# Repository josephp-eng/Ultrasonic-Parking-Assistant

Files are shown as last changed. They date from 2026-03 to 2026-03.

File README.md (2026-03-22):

# STM32 Ultrasonic Parking Assistant
**Author:** Joseph Pokuta

**Course:** Embedded Microcontrollers (EE3174) | Michigan Technological University

**Date:** 12/03/25

System Demo

This project implements a real-time distance-sensing parking aid designed for the STM32L152RE (ARM Cortex-M3) platform. The system provides immediate visual and auditory feedback to assist drivers in obstructed or low-visibility environments. It was developed as a complete embedded solution, spanning from initial KiCad schematic design to a hand-soldered hardware prototype.

Uses buzzers, lights, an LCD screen, and an ultrasonic sensor to provide a simple yet effective reverse-parking assistant.

*This project was completed for my Embedded Microcontrollers class at Michigan Tech. Be aware that the project files are named with 'EE3174' and 'JP' exactly how they were submitted for the class.*

## System Capabilities
* **Dynamic Range Calibration:** A 10k potentiometer is polled via ADC1 to set the "STOP" distance threshold (20cm - 150cm) in real time.
* **Signal Conditioning:** Implements a median-of-3 filter to eliminate ultrasonic sensor noise and software hysteresis to prevent LED/LCD flickering at band boundaries.
* **Contextual User Interface:** A single interrupt-driven button supports short-press (Mute) and long-press (System Enable/Disable) actions.
* **Non-Blocking Logic:** The buzzer PWM and LCD I2C updates are managed via state-machine logic to ensure the system remains responsive without utilizing CPU-halting delays.

| State | Visual | Description |
| :--- | :--- | :--- |
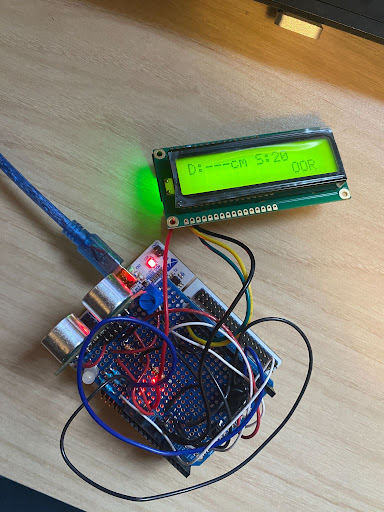
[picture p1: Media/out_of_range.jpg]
Out of Range
| **Out of Range (OOR)** |  | Active when objects are >60cm away. The system enters a low-activity state to prevent needless power draw and noise. |
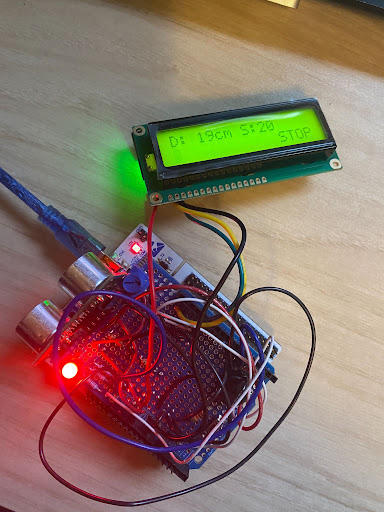
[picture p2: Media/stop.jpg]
Stop State
| **Optimal Stop** |  | Indicates the vehicle has reached the precise "Stop" distance (e.g., 20cm) as calibrated by the user via the potentiometer. |

## Hardware Spec
The hardware was designed in KiCad and hand-soldered onto a protoboard shield.

[Hardware Schematic](Media/project_layout.jpg)

### Pin Mapping
| Peripheral | STM32 Pin | Mode | Purpose |
| :--- | :--- | :--- | :--- |
| **HC-SR04 Echo** | PA0 | TIM2 Input Capture | Measures pulse width for distance calculation |
| **HC-SR04 Trig** | PA9 | GPIO Output | Generates 12us trigger pulse |
| **I2C LCD** | PB8 / PB9 | I2C1 | Interface for MCP23008 Port Expander |
| **RGB LED** | PB13 - PB15 | GPIO Output | Tri-color visual proximity indicator |
| **Buzzer** | PB4 | TIM3 CH1 (PWM) | Variable frequency audio feedback |
| **Potentiometer** | PA4 | ADC1 | Real-time "Stop" threshold calibration |
| **User Button** | PA8 | EXTI (Interrupt) | Short press: Mute / Long press: Power |

### Bill of Materials
* 1x STM32L152RE Nucleo-64
* 1x HC-SR04 Ultrasonic Sensor
* 1x 16x2 Character LCD (I2C)
* 1x Common-Anode RGB LED
* 1x Piezo Buzzer
* 1x 10k Ohm Potentiometer
* 1x Momentary Tactile Switch
* 1x Protoboard Shield

## Challenges and Debugging
The transition from schematic to a soldered prototype involved significant hardware troubleshooting:
* **Voltage Rail Optimization:** Initial smoke testing revealed that the HC-SR04 and I2C LCD were underperforming on the 3.3V rail. The power domain was shifted to 5V while maintaining logic compatibility with the STM32's 5V-tolerant pins, resulting in stable sensor pings and clear LCD contrast.
* **Hardware Isolation:** A grounding failure on the piezo buzzer was identified late in the assembly phase. By isolating the buzzer subsystem and performing continuity tests, the fault was traced to a cold solder joint on the common ground plane and rectified.
* **OOR Logic:** Specialized handling was implemented for Out-of-Range measurements to prevent the system from reporting "ghost" distances or running the UI unnecessarily when the path is clear.

### Logic Flow
```mermaid
graph TD
    A[Start] --> B[Initialize Peripherals]
    B --> C[Self-Test: Buzzer Chirp]
    C --> D[Loop]
    D --> E[Read ADC: Update Stop Threshold]
    E --> F[Trigger HC-SR04 Sensor]
    F --> G[TIM2 Capture: Pulse Calculation]
    G --> H[Apply Median Filter & Hysteresis]
    H --> I{Distance Analysis}
    I --> J[Update RGB LED & Buzzer PWM]
    J --> K[Update LCD Cache]
    K --> D
```

## How to Run

### Hardware
* Wire the components according the to **Pin Mapping** table and the KiCad schematic `project_layout.jpg`
* Connect the STM32 Nucleo-64 board via Mini-USB to your device

### Software
* Open **STM32CubeIDE**.
* Import the project from the `/final_parkingAssistant_JP` directory.
* Open the `.ioc` file to verify the Clock Configuration (ensure the HCLK is set correctly for the Timer prescalers).
* Build the project to generate the `.elf` or `.bin` file.
* Connect your Nucleo board and click **Run** to flash the firmware.

### Usage
* Upon startup, the system will perform a short buzzer "chirp" to confirm the PWM and Piezo are functional.
* Adjust the **Potentiometer** to set your desired stopping distance.
* Use the **Button** to toggle the mute state ('M') or long-press to enter standby mode.

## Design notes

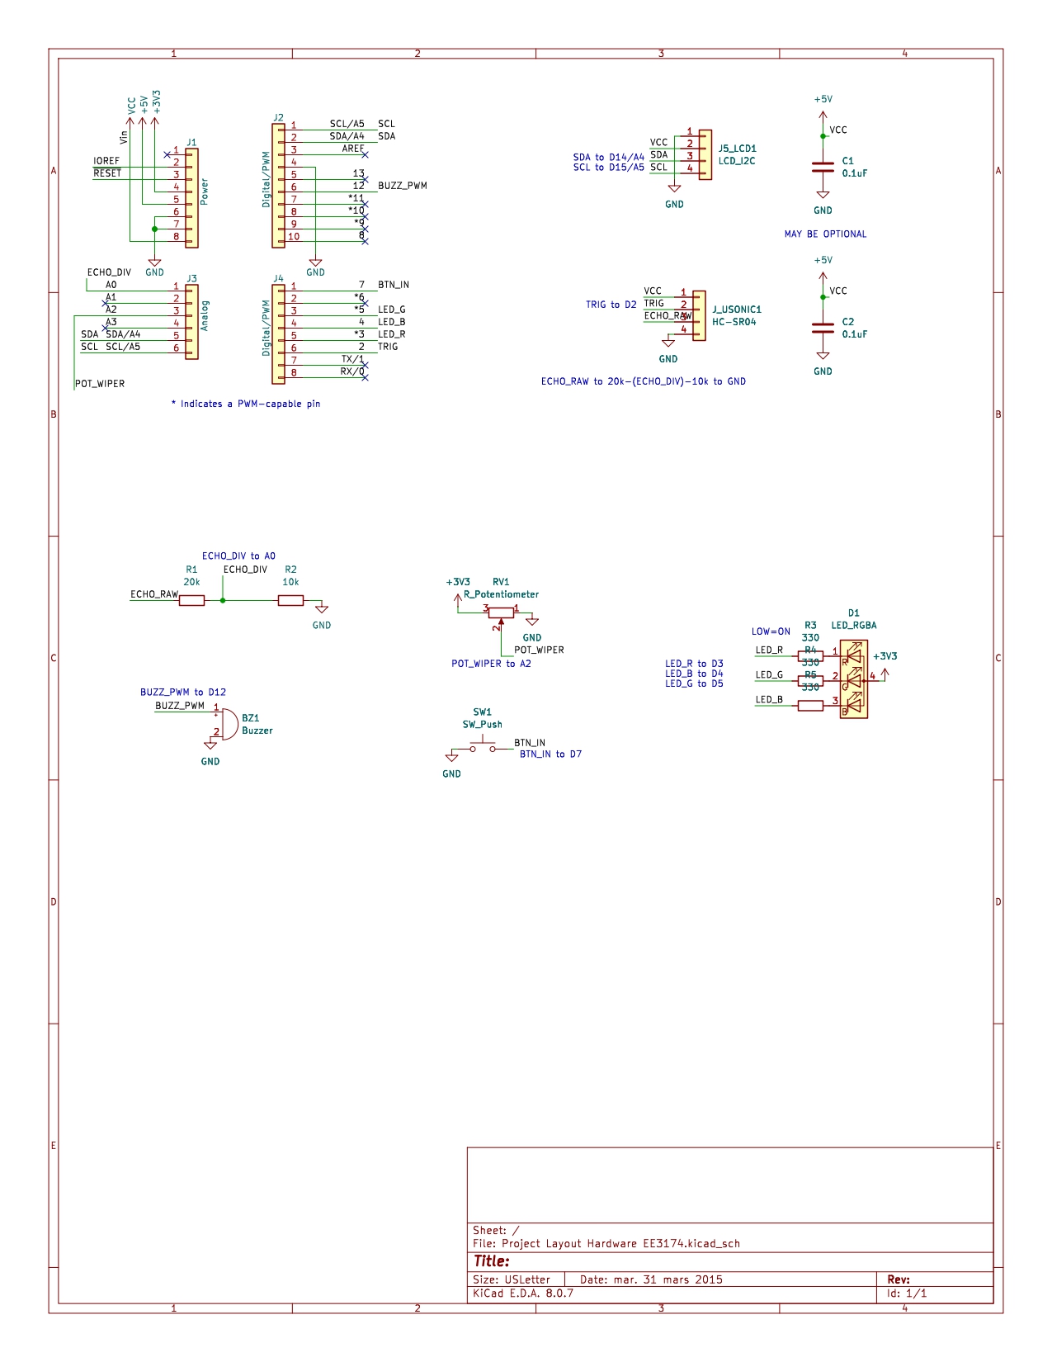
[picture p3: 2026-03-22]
Media/project_layout.jpg

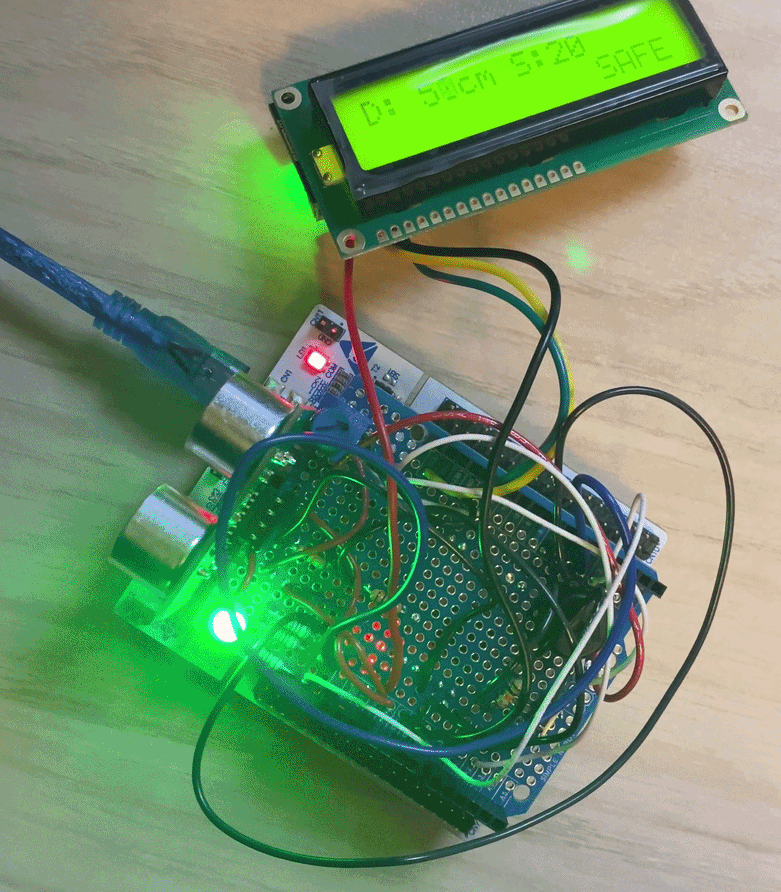
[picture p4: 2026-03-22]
Media/good.png

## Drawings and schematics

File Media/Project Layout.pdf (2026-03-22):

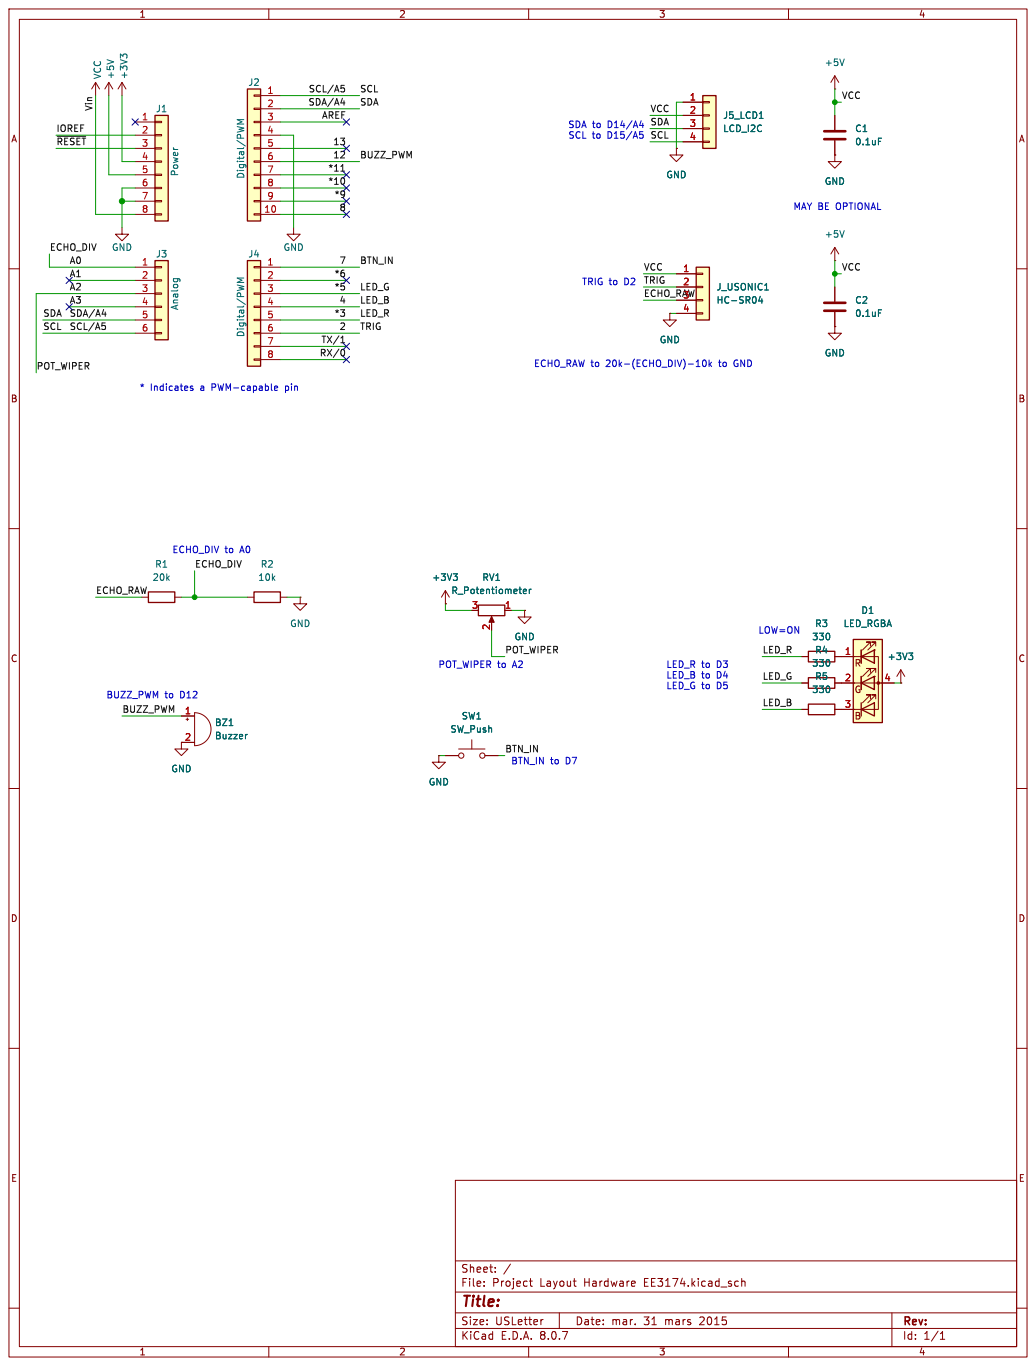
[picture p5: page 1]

SDA to D14/A4 SCL to D15/A5

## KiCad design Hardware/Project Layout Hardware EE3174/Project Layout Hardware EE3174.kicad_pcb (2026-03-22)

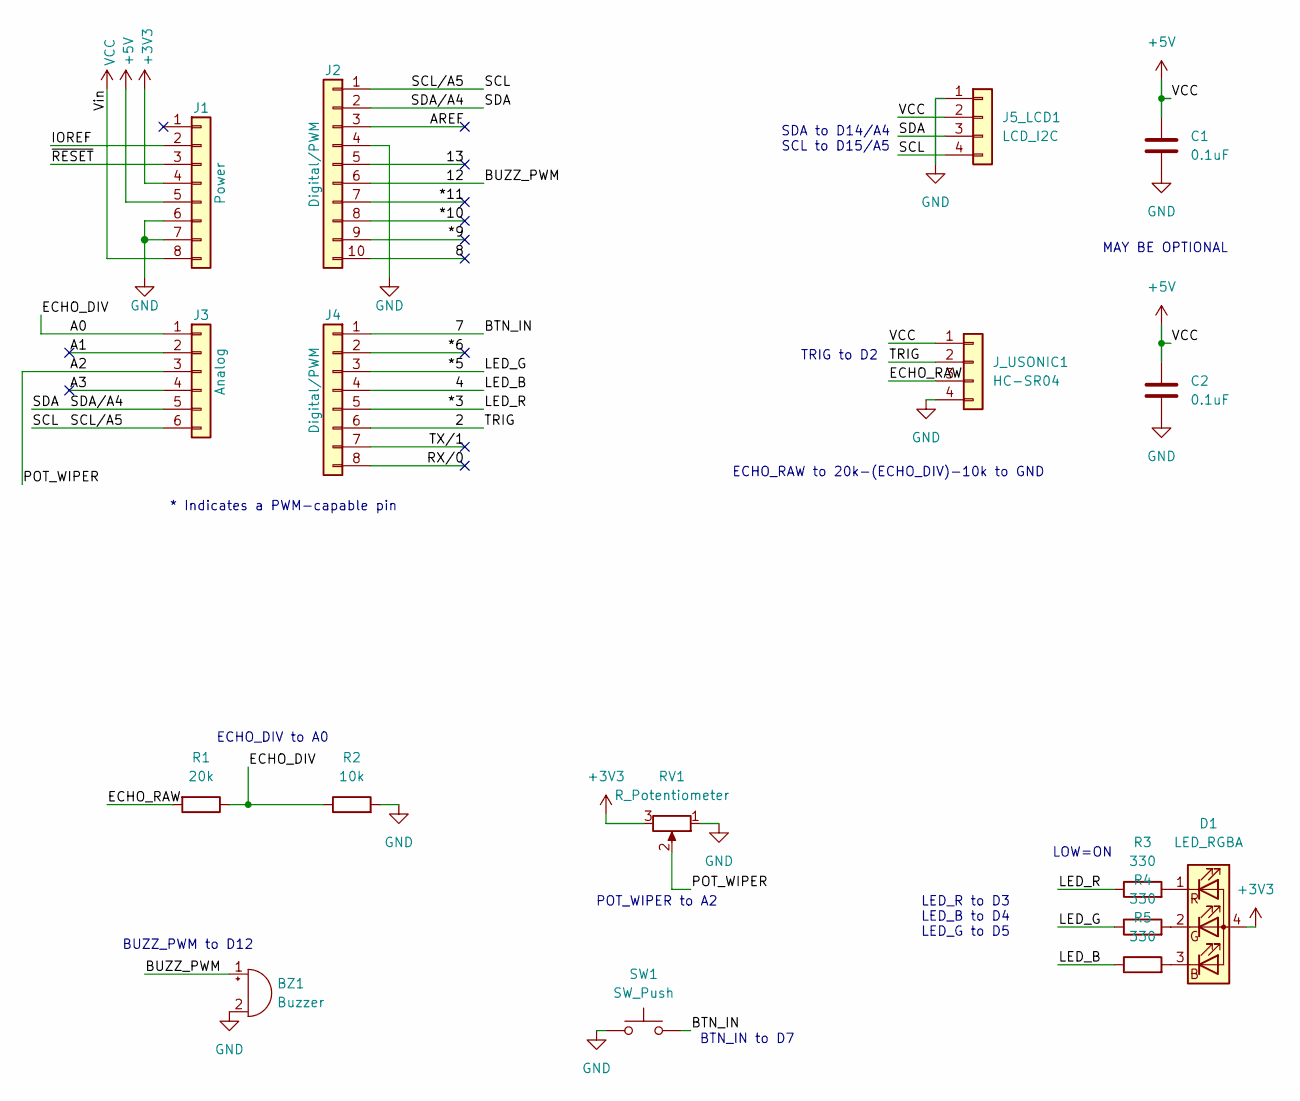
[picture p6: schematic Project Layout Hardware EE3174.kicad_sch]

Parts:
BZ1: Buzzer; Buzzer_12x9.5RM7.6
C1, C2: 0.1uF; C_Disc_D3.0mm_W2.0mm_P2.50mm
D1: LED_RGBA; LED_D5.0mm-4_RGB
J1: Power; PinSocket_1x08_P2.54mm_Vertical
J2: Digital/PWM; PinSocket_1x10_P2.54mm_Vertical
J3: Analog; PinSocket_1x06_P2.54mm_Vertical
J4: Digital/PWM; PinSocket_1x08_P2.54mm_Vertical
J5_LCD1: LCD_I2C; PinHeader_1x04_P2.54mm_Vertical
J_USONIC1: HC-SR04; PinHeader_1x04_P2.54mm_Vertical
R1: 20k; R_Axial_DIN0207_L6.3mm_D2.5mm_P7.62mm_Horizontal
R2: 10k; R_Axial_DIN0207_L6.3mm_D2.5mm_P7.62mm_Horizontal
R3, R4, R5: 330; R_Axial_DIN0207_L6.3mm_D2.5mm_P7.62mm_Horizontal
RV1: R_Potentiometer; Potentiometer_Alps_RK09K_Single_Vertical
SW1: SW_Push; SW_PUSH_6mm

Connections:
+3V3: D1.4 (A), J1.4, RV1.3
+5V: C1.1, C2.1, J1.5, J1.8, J5_LCD1.2, J_USONIC1.1 (VCC)
/2: J4.6, J_USONIC1.2 (TRIG)
/4: J4.4, R5.1
/7: J4.1, SW1.2
/8: J2.10
/12: BZ1.1 (+), J2.6
/13: J2.5
/*3: J4.5, R3.1
/*5: J4.3, R4.1
/*6: J4.2
/*9: J2.9
/*10: J2.8
/*11: J2.7
/A0: J3.1, R1.1, R2.1
/A1: J3.2
/A2: J3.3, RV1.2
/A3: J3.4
/AREF: J2.3
/ECHO_RAW: J_USONIC1.3 (ECHO), R1.2
/IOREF: J1.2
/RX/0: J4.8
/SCL: J2.1, J3.6, J5_LCD1.4
/SDA: J2.2, J3.5, J5_LCD1.3
/TX/1: J4.7
/~RESET: J1.3
GND: BZ1.2 (-), C1.2, C2.2, J1.6, J1.7, J2.4, J5_LCD1.1, J_USONIC1.4 (GND), R2.2, RV1.1, SW1.1
unnamed: D1.3 (BK), R5.2
unnamed: D1.2 (GK), R4.2
unnamed: D1.1 (RK), R3.2

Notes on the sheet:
BUZZ_PWM to D12
MAY BE OPTIONAL
TRIG to D2
BTN_IN to D7
SDA to D14/A4 SCL to D15/A5
LED_R to D3 LED_B to D4 LED_G to D5
ECHO_DIV to A0
LOW=ON
* Indicates a PWM-capable pin
ECHO_RAW to 20k-(ECHO_DIV)-10k to GND
POT_WIPER to A2

Board: 2 copper layers, 21 parts (0 on the bottom side), 17 nets, no tracks yet.

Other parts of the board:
MH1, MH2, MH3, MH4: MountingHole_3.2mm

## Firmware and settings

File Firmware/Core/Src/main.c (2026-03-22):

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
/* Includes ------------------------------------------------------------------*/
#include "main.h"

/* USER CODE BEGIN Includes */
#include <stdio.h>
#include <string.h>
/* USER CODE END Includes */

/* USER CODE BEGIN PD */
// ---- UI / logic constants ----
// Hysteresis for OOR: once you're "out", you must come back below OOR_EXIT_CM to re-enter range.
#define OOR_ENTER_CM    60    // distance >= this -> go OOR
#define OOR_EXIT_CM     56    // distance <= this -> back in range

#define OUT_MAX_CM      OOR_ENTER_CM   // leave this name for existing code paths (LCD/buzzer)
#define SLOW_BAND_CM    25    // stop_cm..stop_cm+25 = "SLOW"; else "SAFE"
#define BAR_LEN         12    // meter cells on 2nd line
#define DEBOUNCE_MS     40
#define LONG_PRESS_MS   700   // hold >= this => enable/disable toggle


/* USER CODE END PD */

ADC_HandleTypeDef hadc;

I2C_HandleTypeDef hi2c1;

TIM_HandleTypeDef htim2;
TIM_HandleTypeDef htim3;

UART_HandleTypeDef huart2;

/* USER CODE BEGIN PV */
// ---- Ultrasonic shared state (EXTI + TIM2) ----
volatile uint32_t t_rise = 0, t_fall = 0;
volatile uint8_t  echo_done = 0;       // set on falling edge
volatile uint32_t us_pulse = 0;        // pulse width in us
volatile uint16_t cm10     = 0;        // distance in 0.1 cm (integer)

// ---- Pot values ----
volatile uint16_t pot_raw = 0;         // 0..4095
volatile uint16_t stop_cm = 60;        // user "stop" setpoint (cm), from pot

// ---- Buzzer pattern (non-blocking) ----
uint32_t beep_next_ms = 0;
uint16_t beep_on_ms   = 60;
uint16_t beep_off_ms  = 300;

// ---- App state ----
volatile uint8_t  system_enabled = 1;   // long-press toggles this
volatile uint8_t  buzzer_muted   = 0;   // short-press toggles this

// ---- Button (PA8) edge tracking ----
volatile uint8_t  btn_down = 0;
volatile uint32_t btn_t0   = 0;

// ---- MCP23008 LCD port mirror (backlight on) ----
static uint8_t mcp_port = (1u<<7);     // LCD_BL

// Line caches to avoid flicker (16 chars + NUL)
static char line0_prev[17] = "                ";
static char line1_prev[17] = "                ";
static uint32_t next_lcd_ms = 0;

/* USER CODE END PV */

void SystemClock_Config(void);
static void MX_GPIO_Init(void);
static void MX_USART2_UART_Init(void);
static void MX_ADC_Init(void);
static void MX_I2C1_Init(void);
static void MX_TIM2_Init(void);
static void MX_TIM3_Init(void);
/* USER CODE BEGIN PFP */
// microsecond delay via DWT
static void delay_us(uint32_t us);

// ultrasonic
static void usonic_timer_start(void);
static uint8_t usonic_single(void);   // fills us_pulse & cm10, returns 1 if ok

// pot
static uint16_t pot_read_raw(void);
static uint16_t pot_to_stop_cm(uint16_t v); // map 0..4095 -> 20..150 cm

// RGB & buzzer
static void rgb_set(uint8_t r_on, uint8_t g_on, uint8_t b_on); // 1=ON
static void buzzer_on(void);
static void buzzer_off(void);
static void buzzer_update(uint32_t now_ms, uint16_t dist_cm);

// UI helpers (only the drawer is prototyped here;
// lcd_write_line_cached() is defined before use in USER CODE 0)
static void lcd_draw_ui(uint16_t dist_cm, uint16_t stop_cm, uint8_t muted, uint8_t enabled);

// LCD (MCP23008 @ 0x20)
static void lcd_i2c_scan(void);
static HAL_StatusTypeDef mcp_write(uint8_t reg, uint8_t val);
static void mcp_apply(void);
static void lcd_pulseE(void);
static void lcd_write4(uint8_t nibble, uint8_t rs);
static void lcd_write8(uint8_t v, uint8_t rs);
static void lcd_cmd(uint8_t c);
static void lcd_data(uint8_t d);
static void lcd_init_4bit(void);
static void lcd_set_cursor(uint8_t col, uint8_t row);
static void lcd_print(const char *s);
static void lcd_print_u16(uint16_t v);
static void lcd_bar16(uint8_t filled);
static void lcd_clear_line(uint8_t row);
/* USER CODE END PFP */

/* USER CODE BEGIN 0 */
// ---- microsecond delay via DWT cycle counter ----
static void delay_us(uint32_t us){
  static uint8_t ready = 0;
  if(!ready){
    CoreDebug->DEMCR |= CoreDebug_DEMCR_TRCENA_Msk;
    DWT->CYCCNT = 0;
    DWT->CTRL  |= DWT_CTRL_CYCCNTENA_Msk;
    ready = 1;
  }
  const uint32_t cycles_per_us = 32000000u/1000000u; // SYSCLK ~32 MHz
  uint32_t start = DWT->CYCCNT, target = start + us*cycles_per_us;
  while((int32_t)(DWT->CYCCNT - target) < 0) { __NOP(); }
}

// ---- Ultrasonic helpers ----
static void usonic_timer_start(void){
  // TIM2 is Base @ 1 MHz (PSC=31, ARR=65535)
  __HAL_TIM_SET_PRESCALER(&htim2, 31);
  __HAL_TIM_SET_AUTORELOAD(&htim2, 65535);
  __HAL_TIM_SET_COUNTER(&htim2, 0);
  HAL_TIM_Base_Start(&htim2);
  // TRIG idle low
  HAL_GPIO_WritePin(TRIG_GPIO_Port, TRIG_Pin, GPIO_PIN_RESET);
}

// one shot: returns 1 if echo captured, updates us_pulse and cm10
static uint8_t usonic_single(void){
  echo_done = 0;
  // 10–12 us TRIG
  HAL_GPIO_WritePin(TRIG_GPIO_Port, TRIG_Pin, GPIO_PIN_SET);
  delay_us(12);
  HAL_GPIO_WritePin(TRIG_GPIO_Port, TRIG_Pin, GPIO_PIN_RESET);

  // wait up to 40 ms
  uint32_t t0 = HAL_GetTick();
  while(!echo_done){
    if (HAL_GetTick() - t0 > 40) return 0;
  }
  uint32_t arr = __HAL_TIM_GET_AUTORELOAD(&htim2) + 1;
  us_pulse = (t_fall >= t_rise) ? (t_fall - t_rise) : (t_fall + arr - t_rise);
  // distance in 0.1 cm: (us / 58) * 10 = us * 10 / 58
  cm10 = (uint16_t)((us_pulse * 10u) / 58u);
  return 1;
}

// ---- Potentiometer ----
static uint16_t pot_read_raw(void){
  HAL_ADC_Start(&hadc);
  HAL_ADC_PollForConversion(&hadc, 5);
  uint16_t v = (uint16_t)HAL_ADC_GetValue(&hadc);
  HAL_ADC_Stop(&hadc);
  return v;
}
// map 0..4095 -> 20..150 cm (linear)
static uint16_t pot_to_stop_cm(uint16_t v){
  if (v > 4095) v = 4095;
  return (uint16_t)(20u + ((150u - 20u) * (uint32_t)v)/4095u);
}

// ---- RGB (common-anode: LOW=ON) ----
static void rgb_set(uint8_t r_on, uint8_t g_on, uint8_t b_on){
  // drive low to turn ON
  HAL_GPIO_WritePin(RGB_LED1_GPIO_Port, RGB_LED1_Pin, r_on ? GPIO_PIN_RESET : GPIO_PIN_SET);
  HAL_GPIO_WritePin(RGB_LED2_GPIO_Port, RGB_LED2_Pin, g_on ? GPIO_PIN_RESET : GPIO_PIN_SET);
  HAL_GPIO_WritePin(RGB_LED3_GPIO_Port, RGB_LED3_Pin, b_on ? GPIO_PIN_RESET : GPIO_PIN_SET);
}

// ---- Buzzer @ 2 kHz (TIM3 CH1; CCR=50% when ON) ----
static void buzzer_on(void){
  __HAL_TIM_SET_COMPARE(&htim3, TIM_CHANNEL_1, (__HAL_TIM_GET_AUTORELOAD(&htim3)+1)/2);
  HAL_TIM_PWM_Start(&htim3, TIM_CHANNEL_1);
}
static void buzzer_off(void){
  HAL_TIM_PWM_Stop(&htim3, TIM_CHANNEL_1);
}
// --- small median-of-3 helper (robust to one outlier) ---
static uint16_t median3(uint16_t a, uint16_t b, uint16_t c)
{
  if (a > b) { uint16_t t=a; a=b; b=t; }
  if (b > c) { uint16_t t=b; b=c; c=t; }
  if (a > b) { uint16_t t=a; a=b; b=t; }
  return b; // now b is median
}

// ---- UI + LED helpers ------------------------------------------------------

// Color enum and LED setter (common-anode: LOW = ON)
typedef enum { LED_OFF=0, LED_GREEN, LED_YELLOW, LED_RED } LEDColor;

static void set_led_color(LEDColor c)
{
  switch (c) {
    case LED_OFF:    rgb_set(0,0,0); break;
    case LED_GREEN:  rgb_set(0,1,0); break;
    case LED_YELLOW: rgb_set(1,1,0); break; // red+green
    case LED_RED:    rgb_set(1,0,0); break;
  }
}

// Write a full 16-char line only if contents changed (reduces flicker)
static void lcd_write_line_cached(uint8_t row, const char *line16, char prev16[17])
{
  // compare
  if (memcmp(prev16, line16, 16) == 0) return;

  // write
  lcd_set_cursor(0, row);
  for (uint8_t i = 0; i < 16; ++i) {
    lcd_data((uint8_t)line16[i]);
  }

  // cache
  memcpy(prev16, line16, 16);
  prev16[16] = '\0';
}

// Line0: "D:XXcm S:YY " + 'M' at col 15
// Line1: [BAR] + "SAFE/SLOW/STOP" or "OOR "
static void lcd_draw_ui(uint16_t dist_cm, uint16_t stop_cm, uint8_t muted, uint8_t enabled)
{
  extern char line0_prev[17];
  extern char line1_prev[17];
  extern uint32_t next_lcd_ms;

  uint32_t now = HAL_GetTick();
  if ((int32_t)(now - next_lcd_ms) < 0) return;  // rate-limit
  next_lcd_ms = now + 50;                         // ~20 Hz max

  char l0[17]; char l1[17];
  memset(l0, ' ', 16); l0[16] = '\0';
  memset(l1, ' ', 16); l1[16] = '\0';

  if (!enabled) {
    lcd_write_line_cached(0, l0, line0_prev);
    lcd_write_line_cached(1, l1, line1_prev);
    return;
  }

  // ----- Line 0 -----
  const uint8_t invalid = (dist_cm == 999 || dist_cm > OUT_MAX_CM);
  char dstr[4] = "---";
  if (!invalid) snprintf(dstr, sizeof dstr, "%3u", dist_cm);
  char sstr[4]; snprintf(sstr, sizeof sstr, "%-3u", stop_cm);

  l0[0]='D'; l0[1]=':'; memcpy(&l0[2], dstr, 3);
  l0[5]='c'; l0[6]='m'; l0[7]=' ';
  l0[8]='S'; l0[9]=':'; memcpy(&l0[10], sstr, 3);
  l0[15] = muted ? 'M' : ' ';

  // ----- Line 1 -----
  if (invalid) {
    memcpy(&l1[12], "OOR ", 4);
  } else {
    int16_t remain = (int16_t)stop_cm - (int16_t)dist_cm; // >0 when closer than setpoint
    uint8_t fill = (remain <= 0) ? 0 :
                   (remain >= (BAR_LEN*2) ? BAR_LEN : (uint8_t)(remain/2));
    for (uint8_t i=0;i<BAR_LEN && i<16;i++) l1[i] = (i<fill) ? (char)0xFF : ' ';

    const char* status =
      (dist_cm <= stop_cm) ? "STOP" :
      (dist_cm < (uint16_t)(stop_cm + SLOW_BAND_CM)) ? "SLOW" : "SAFE";
    memcpy(&l1[12], status, 4); // fits at columns 12..15
  }

  // push if changed
  lcd_write_line_cached(0, l0, line0_prev);
  lcd_write_line_cached(1, l1, line1_prev);
}


// Final cadence: SAFE = very infrequent, SLOW = ~1 Hz, STOP = continuous tone
static void buzzer_update(uint32_t now_ms, uint16_t dist_cm)
{
  // Global guards
  if (!system_enabled || buzzer_muted || dist_cm == 999 || dist_cm > OUT_MAX_CM) {
    buzzer_off();
    // don't reset state; when re-enabled we’ll re-sync on zone change
    return;
  }

  // Zone selection
  enum { Z_SAFE=0, Z_SLOW, Z_STOP } zone;
  if (dist_cm <= stop_cm) {
    zone = Z_STOP;                 // RED
  } else if (dist_cm < (uint16_t)(stop_cm + SLOW_BAND_CM)) {
    zone = Z_SLOW;                 // YELLOW
  } else {
    zone = Z_SAFE;                 // GREEN
  }

  // Persistent state
  static uint8_t  phase_on = 0;    // 0 = OFF, 1 = ON (for chirps)
  static uint32_t t_next   = 0;    // next toggle timestamp
  static uint8_t  last_zone = 0xFF;

  // STOP => continuous tone
  if (zone == Z_STOP) {
    if (last_zone != Z_STOP) {
      // entering STOP: turn solid ON
      buzzer_on();
      phase_on  = 1;
      // t_next unused while in STOP
    }
    last_zone = Z_STOP;
    return; // keep buzzing continuously
  }

  // If we just left STOP, ensure we start from OFF to make chirps clear
  if (last_zone == Z_STOP && zone != Z_STOP) {
    buzzer_off();
    phase_on = 0;
    t_next   = now_ms; // ready to start new cadence
  }
  last_zone = zone;

  // Per-zone ON/OFF timings (ms)
  // SAFE: ~0.33 Hz => 60 ms ON, 2940 ms OFF (very infrequent)
  // SLOW: ~1.0  Hz => 120 ms ON, 880  ms OFF (clearly more frequent)
  uint16_t on_ms, off_ms;
  if (zone == Z_SLOW) {
    on_ms = 120; off_ms = 880;
  } else { // Z_SAFE
    on_ms = 60;  off_ms = 2940;
  }

  // Initialize first chirp promptly when entering a chirp zone
  static uint8_t initialized = 0;
  if (!initialized) {
    initialized = 1;
    phase_on = 1;
    buzzer_on();
    t_next = now_ms + on_ms;
  }

  // Toggle by schedule
  if ((int32_t)(now_ms - t_next) >= 0) {
    if (phase_on) {
      // go OFF for the rest period
      buzzer_off();
      phase_on = 0;
      t_next = now_ms + off_ms;
    } else {
      // start a chirp
      buzzer_on();
      phase_on = 1;
      t_next = now_ms + on_ms;
    }
  }
}


// ---- LCD (MCP23008 @ 0x20) ----
#define LCD_RS   (1u<<1)
#define LCD_E    (1u<<2)
#define LCD_D4   (1u<<3)
#define LCD_D5   (1u<<4)
#define LCD_D6   (1u<<5)
#define LCD_D7   (1u<<6)
#define LCD_BL   (1u<<7)
#define MCP_ADDR (0x20u<<1)
#define MCP_IODIR 0x00
#define MCP_GPIO  0x09

static void lcd_i2c_scan(void){
  volatile uint8_t seen = 0;
  for(uint8_t a=0x03;a<0x78;a++){
    if(HAL_I2C_IsDeviceReady(&hi2c1, a<<1, 1, 5)==HAL_OK){
      if (a==0x20) seen=1;
    }
  }
  (void)seen; // set a breakpoint to verify seen==1
}
static HAL_StatusTypeDef mcp_write(uint8_t reg, uint8_t val){
  uint8_t buf[2] = {reg, val};
  return HAL_I2C_Master_Transmit(&hi2c1, MCP_ADDR, buf, 2, 50);
}
static void mcp_apply(void){ (void)mcp_write(MCP_GPIO, mcp_port); }
static void lcd_pulseE(void){
  mcp_port |= LCD_E;  mcp_apply();
  for(volatile int i=0;i<160;i++) __NOP();
  mcp_port &= ~LCD_E; mcp_apply();
}
static void lcd_write4(uint8_t nibble, uint8_t rs){
  mcp_port &= ~(LCD_D4|LCD_D5|LCD_D6|LCD_D7|LCD_RS);
  if (rs) mcp_port |= LCD_RS;
  if (nibble & 0x01) mcp_port |= LCD_D4;
  if (nibble & 0x02) mcp_port |= LCD_D5;
  if (nibble & 0x04) mcp_port |= LCD_D6;
  if (nibble & 0x08) mcp_port |= LCD_D7;
  mcp_apply();
  lcd_pulseE();
}
static void lcd_write8(uint8_t v, uint8_t rs){
  lcd_write4((v>>4)&0x0F, rs);
  lcd_write4( v    &0x0F, rs);
}
static void lcd_cmd(uint8_t c){ lcd_write8(c, 0); HAL_Delay(2); }
static void lcd_data(uint8_t d){ lcd_write8(d, 1); }
static void lcd_init_4bit(void){
  (void)mcp_write(MCP_IODIR, 0x00);
  mcp_port = LCD_BL; mcp_apply();
  HAL_Delay(50);
  lcd_write4(0x03,0); HAL_Delay(5);
  lcd_write4(0x03,0); HAL_Delay(5);
  lcd_write4(0x03,0); HAL_Delay(1);
  lcd_write4(0x02,0); HAL_Delay(1);  // 4-bit
  lcd_cmd(0x28); // 4-bit, 2-line, 5x8
  lcd_cmd(0x08); // display off
  lcd_cmd(0x01); HAL_Delay(2);
  lcd_cmd(0x06); // entry mode
  lcd_cmd(0x0C); // display on
}
static void lcd_set_cursor(uint8_t col, uint8_t row){
  static const uint8_t rowaddr[] = {0x00, 0x40, 0x14, 0x54};
  if (row>1) row=1;
  lcd_cmd(0x80 | (rowaddr[row] + col));
}
static void lcd_print(const char *s){ while(*s) lcd_data((uint8_t)*s++); }
static void lcd_print_u16(uint16_t v){
  char buf[6]; // up to 65535
  int i=5; buf[i--]='\0';
  if(v==0){ lcd_data('0'); return; }
  while(v && i>=0){ buf[i--] = '0'+(v%10); v/=10; }
  lcd_print(&buf[i+1]);
}
// simple 0..BAR_LEN bar on row 2
static void lcd_bar16(uint8_t filled){
  if (filled>BAR_LEN) filled=BAR_LEN;
  for(uint8_t i=0;i<BAR_LEN;i++) lcd_data(i<filled ? 0xFF : ' ');
}

static void lcd_clear_line(uint8_t row){
  lcd_set_cursor(0,row);
  lcd_print("                "); // 16 spaces
  lcd_set_cursor(0,row);
}


/* USER CODE END 0 */

/**
  * @brief  The application entry point.
  * @retval int
  */
int main(void)
{

  /* MCU Configuration--------------------------------------------------------*/

  /* Reset of all peripherals, Initializes the Flash interface and the Systick. */
  HAL_Init();

  /* Configure the system clock */
  SystemClock_Config();

  /* Initialize all configured peripherals */
  MX_GPIO_Init();
  MX_USART2_UART_Init();
  MX_ADC_Init();
  MX_I2C1_Init();
  MX_TIM2_Init();
  MX_TIM3_Init();
  /* USER CODE BEGIN 2 */
  // RGB off until first valid reading (common-anode => pass zeros)
  rgb_set(0,0,0);

  // I2C presence (optional breakpoint inside)
  lcd_i2c_scan();

  // LCD hello
  lcd_init_4bit();
  lcd_set_cursor(0,0); lcd_print("Parking Assist ");
  lcd_set_cursor(0,1); lcd_print("Init...        ");

  // Ultrasonic timing base + TRIG low
  usonic_timer_start();

  // Pot seed
  pot_raw = pot_read_raw();
  stop_cm = pot_to_stop_cm(pot_raw);

  // Buzzer idle, quick self-test 300 ms
  buzzer_off();
  __HAL_TIM_SET_COMPARE(&htim3, TIM_CHANNEL_1, (__HAL_TIM_GET_AUTORELOAD(&htim3)+1)/2);
  HAL_TIM_PWM_Start(&htim3, TIM_CHANNEL_1);
  HAL_Delay(300);
  HAL_TIM_PWM_Stop(&htim3, TIM_CHANNEL_1);

  // Initial UI paint
  lcd_draw_ui(999, stop_cm, buzzer_muted, system_enabled);
  set_led_color(LED_OFF);

  /* USER CODE END 2 */

  /* Infinite loop */
  /* USER CODE BEGIN WHILE */
  while (1)
  {
    // read pot -> stop_cm
    pot_raw = pot_read_raw();
    stop_cm = pot_to_stop_cm(pot_raw);

    // --- ultrasonic read ---
    uint16_t dist_sample = 999;
    if (usonic_single()) {
      dist_sample = (uint16_t)(cm10/10u);
    }

    // --- 3-sample median filter + OOR hysteresis ---
    static uint16_t d0 = 999, d1 = 999, d2 = 999;   // history
    static uint8_t  oor = 1;                        // start OOR until we see close
    // shift in latest sample (if invalid keep previous values as-is)
    d2 = d1; d1 = d0; d0 = dist_sample;
    uint16_t dist_med = median3(d0, d1, d2);

    // Hysteresis: only flip states when we truly cross the spaced thresholds
    if (oor) {
      if (dist_med <= OOR_EXIT_CM) oor = 0;            // back in range
    } else {
      if (dist_med >= OOR_ENTER_CM) oor = 1;           // go OOR
    }

    // Use 999 to signal "invalid/OOR" to the rest of the UI/buzzer logic
    uint16_t dist_logic = oor ? 999 : dist_med;

    // ----- LED selection -----
    if (!system_enabled || dist_logic == 999) {
      set_led_color(LED_OFF);
    } else if (dist_logic <= stop_cm) {
      set_led_color(LED_RED);
    } else if (dist_logic < (uint16_t)(stop_cm + SLOW_BAND_CM)) {
      set_led_color(LED_YELLOW);
    } else {
      set_led_color(LED_GREEN);
    }

    // ----- Buzzer cadence (handles mute/system/OOR internally) -----
    buzzer_update(HAL_GetTick(), dist_logic);

    // ----- LCD: top line & bar + status (no clears; cached) -----
    lcd_draw_ui(dist_logic, stop_cm, buzzer_muted, system_enabled);

    HAL_Delay(5); // give time to SysTick/EXTI/I2C
  }

  /* USER CODE END 3 */
}

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
/* USER CODE BEGIN 4 */
void HAL_GPIO_EXTI_Callback(uint16_t pin)
{
  // Button on PA8
  if (pin == BTN_IN_Pin) {
    uint32_t now = HAL_GetTick();

    // Read current level to know edge (pull-up idle => HIGH; press => LOW)
    GPIO_PinState level = HAL_GPIO_ReadPin(BTN_IN_GPIO_Port, BTN_IN_Pin);

    if (level == GPIO_PIN_RESET) { // FALLING = press
      if (!btn_down && (now - btn_t0) > DEBOUNCE_MS) {
        btn_down = 1;
        btn_t0   = now;
      }
    } else { // RISING = release
      if (btn_down) {
        btn_down = 0;
        uint32_t dt = now - btn_t0;

        if (dt >= LONG_PRESS_MS) {
          // ---- LONG PRESS: toggle system enabled ----
          system_enabled ^= 1;
          if (!system_enabled) {
            // turn everything off/blank when disabling
            set_led_color(LED_OFF);
            buzzer_off();
            lcd_set_cursor(0,0); lcd_print("                ");
            lcd_set_cursor(0,1); lcd_print("                ");
          } else {
            // redraw when enabling
            lcd_draw_ui(999, stop_cm, buzzer_muted, system_enabled);
          }
        } else if (dt >= DEBOUNCE_MS) {
          // ---- SHORT PRESS: toggle mute ----
          buzzer_muted ^= 1;
          // update 'M' flag immediately
          lcd_set_cursor(15,0); lcd_print(buzzer_muted ? "M" : " ");
        }
      }
    }
    return; // done with button
  }

  // Ultrasonic echo (PA0 via EXTI0)
  if (pin == ECHO_DIV_Pin){
    if (HAL_GPIO_ReadPin(ECHO_DIV_GPIO_Port, ECHO_DIV_Pin) == GPIO_PIN_SET){
      t_rise = __HAL_TIM_GET_COUNTER(&htim2);
      echo_done = 0;
    } else {
      t_fall = __HAL_TIM_GET_COUNTER(&htim2);
      echo_done = 1;
    }
  }
}


/* USER CODE END 4 */
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


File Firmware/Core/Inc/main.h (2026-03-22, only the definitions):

#define B1_Pin GPIO_PIN_13
#define B1_GPIO_Port GPIOC
#define ECHO_DIV_Pin GPIO_PIN_0
#define ECHO_DIV_GPIO_Port GPIOA
#define ECHO_DIV_EXTI_IRQn EXTI0_IRQn
#define USART_TX_Pin GPIO_PIN_2
#define USART_TX_GPIO_Port GPIOA
#define USART_RX_Pin GPIO_PIN_3
#define USART_RX_GPIO_Port GPIOA
#define POT_WIPER_Pin GPIO_PIN_4
#define POT_WIPER_GPIO_Port GPIOA
#define LD2_Pin GPIO_PIN_5
#define LD2_GPIO_Port GPIOA
#define BTN_IN_Pin GPIO_PIN_8
#define BTN_IN_GPIO_Port GPIOA
#define BTN_IN_EXTI_IRQn EXTI9_5_IRQn
#define TRIG_Pin GPIO_PIN_10
#define TRIG_GPIO_Port GPIOA
#define TMS_Pin GPIO_PIN_13
#define TMS_GPIO_Port GPIOA
#define TCK_Pin GPIO_PIN_14
#define TCK_GPIO_Port GPIOA
#define RGB_LED1_Pin GPIO_PIN_3
#define RGB_LED1_GPIO_Port GPIOB
#define RGB_LED2_Pin GPIO_PIN_4
#define RGB_LED2_GPIO_Port GPIOB
#define RGB_LED3_Pin GPIO_PIN_5
#define RGB_LED3_GPIO_Port GPIOB

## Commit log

2026-03-22 Upload Project
    Including STM32CubeIDE code and KiCad project files
    [Project Layout Hardware EE3174.kicad_pcb, Project Layout Hardware EE3174.kicad_sch, freerouting.dsn]
2026-03-22 KiCad Update
2026-03-22 KiCad Directory
    [Project Layout Hardware EE3174.kicad_pcb, Project Layout Hardware EE3174.kicad_sch, freerouting.dsn]

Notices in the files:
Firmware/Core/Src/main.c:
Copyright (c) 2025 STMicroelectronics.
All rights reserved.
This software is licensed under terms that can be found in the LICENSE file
